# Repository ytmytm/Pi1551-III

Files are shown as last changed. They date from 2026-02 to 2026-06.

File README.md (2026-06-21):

# Pi1551-III

A **1551 floppy emulator** for Commodore C16, C116 and Plus/4, in the same mechanical and aesthetic package as the [C64 Pi1541-III](https://github.com/tebl/C64-Pi1541-III): Raspberry Pi 3–based, 1.3" OLED, rotary encoder, and stack of PCBs with faceplates. 

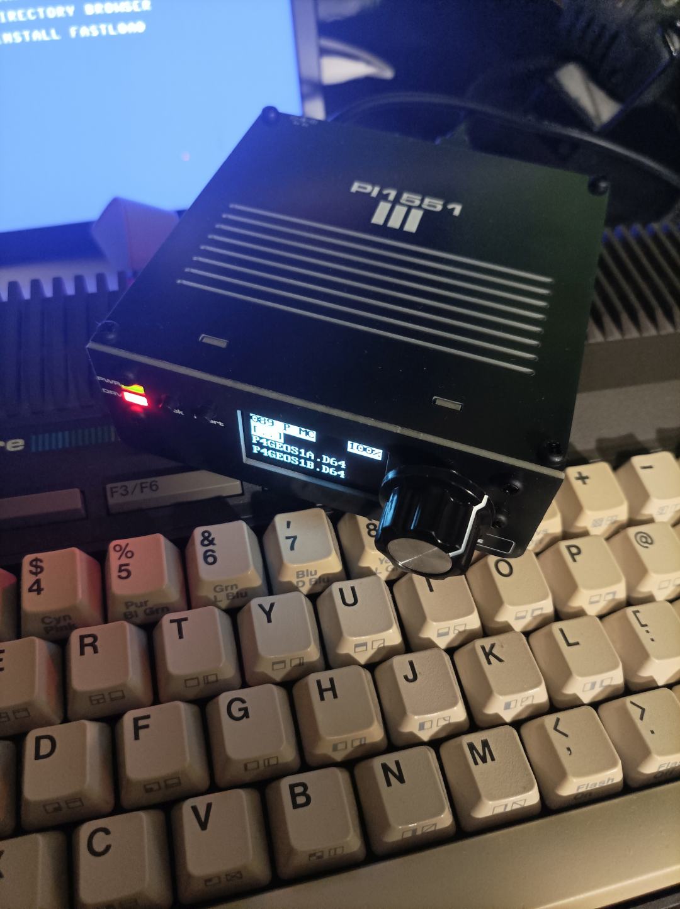
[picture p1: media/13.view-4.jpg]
Front view


This variant uses the **[Pi1551](https://github.com/ytmytm/Pi1551)** firmware and connects to the computer via **[tcbm2sd](https://github.com/ytmytm/plus4-tcbm2sd)** (TCBM bus). It also adds a **MiniDIN-7** port for **TAP tape playback** with a simple 1:1 male-to-male cable to the machine’s tape port.

> **WARNING — tcbm2sd only**  
> This device must **only** be connected to a **tcbm2sd** adapter. **Do not** connect it to an original 1551 paddle or any other 5 V bus. The interface is **not 5 V tolerant** and can damage the Raspberry Pi and the computer.

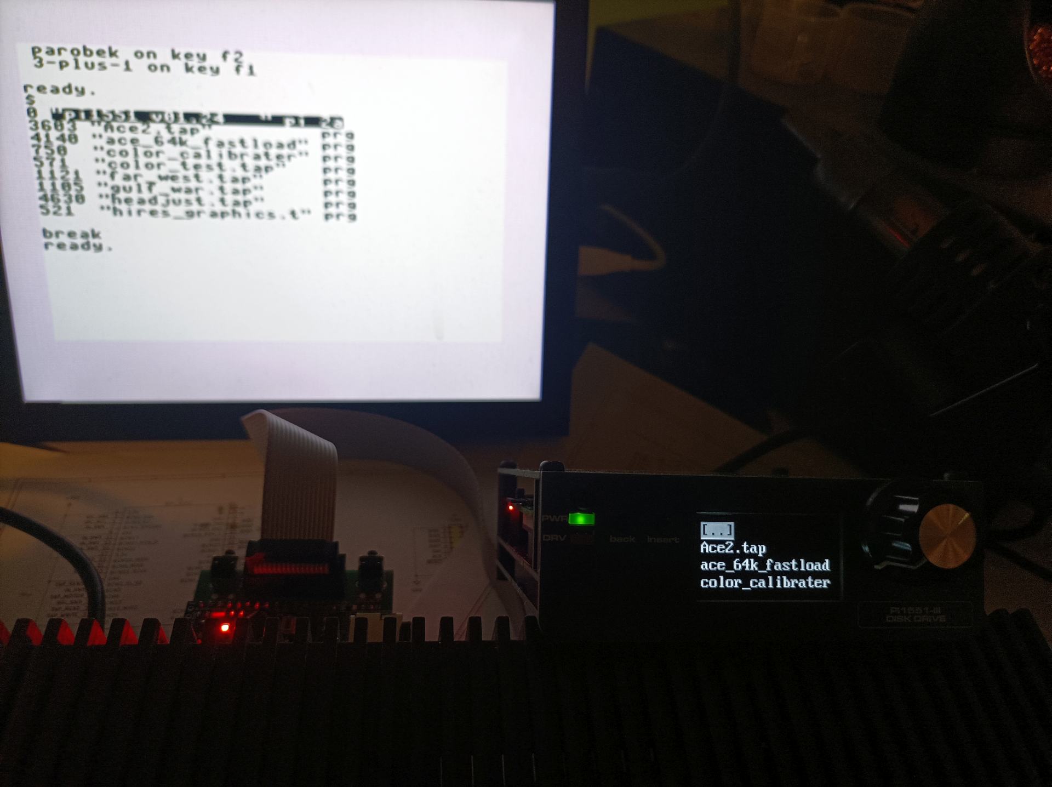
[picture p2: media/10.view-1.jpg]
PI1551-III view

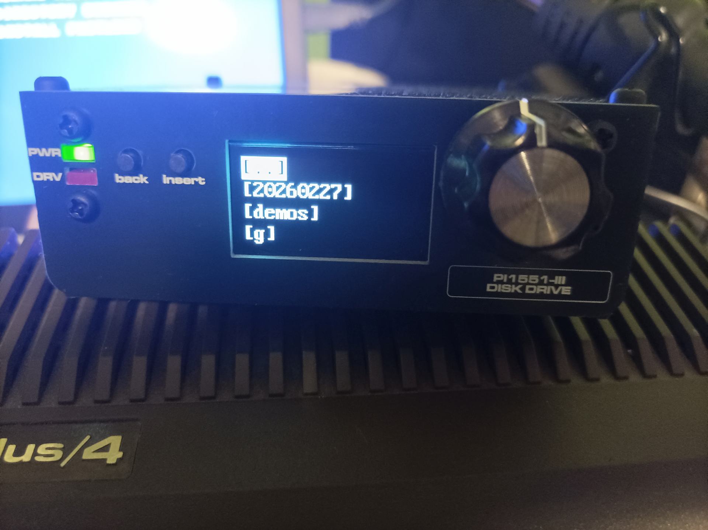
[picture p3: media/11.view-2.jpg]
PI1551-III view

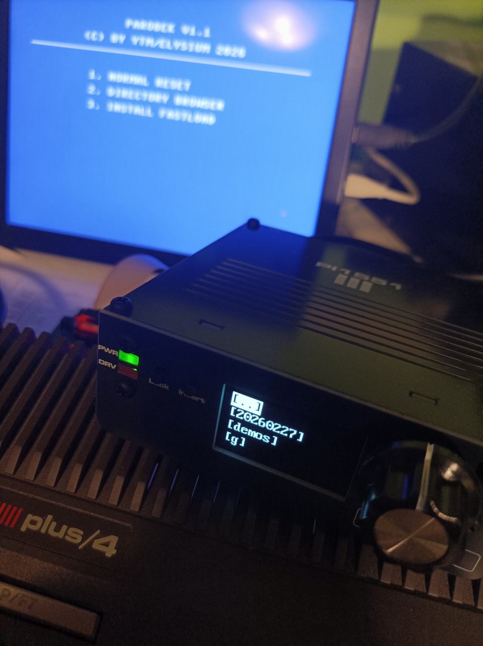
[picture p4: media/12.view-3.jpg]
PI1551-III view


---

**Build files:** Gerbers for every board, plus BOM and SMD position files for the main module (Pi1551-III Module-rotated), are published in the **[Releases](https://github.com/ytmytm/Pi1551-III/releases)** section of this repository.

If you prefer a smaller, simpler board: see **[Pi1551-HAT](https://github.com/ytmytm/Pi1551-HAT)** for a minimal Raspberry Pi HAT with the same 1551 + TAP functionality with several features optional.

---

- [1. Modules](#1-modules)
- [2. Differences from Pi1541-III](#2-differences-from-pi1541-iii)
- [3. Assembly](#3-assembly)
- [4. Cables](#4-cables)
- [5. Documentation](#5-documentation)
- [6. Resources](#6-resources)
- [7. Acknowledgements](#7-acknowledgements)

## 1. Modules

A complete Pi1551-III uses the same five-PCB stack as the Pi1541-III. Assembly and mechanical steps are almost identical, so **use the original project’s gallery and docs** for visual guidance:

- **[C64-Pi1541-III gallery](https://github.com/tebl/C64-Pi1541-III/tree/main/gallery)** — build photos, side views, and assembly reference.

Pi1541-III side view (assembly is the same)
(side view of Pi1541-III, almost identical to Pi1551-III)

| Module | Required | Description | Documentation | Build files |
|---|---|---|---|---|
| [Pi1551-III Module-rotated](Pi1551-III%20Module-rotated) | Yes | Main module: RPi 3, TCBM interface, optional power area (see below), MiniDIN-7 for TAP. | [BOM](Pi1551-III%20Module-rotated/README.md#3-bom) | [Releases](https://github.com/ytmytm/Pi1551-III/releases) |
| [Pi1551-III Module Panel](Pi1551-III%20Module%20Panel) | Yes | Front panel: OLED, rotary encoder, switches. | [BOM](Pi1551-III%20Module%20Panel/README.md#3-bom) | [Releases](https://github.com/ytmytm/Pi1551-III/releases) |
| [Pi1551-III Faceplate (FB1)](faceplates/Pi1551-III%20Module%20FB1) | Yes | Top faceplate; mechanical support for front panel. | — | [Releases](https://github.com/ytmytm/Pi1551-III/releases) |
| [Pi1551-III Faceplate (FB2)](faceplates/Pi1551-III%20Module%20FB2) | Recommended | Bottom faceplate; protects from shorts. | — | [Releases](https://github.com/ytmytm/Pi1551-III/releases) |
| [Pi1551-III Faceplate (FP1)](faceplates/Pi1551-III%20Module%20FP1) | Recommended | Front faceplate; cosmetic. | — | [Releases](https://github.com/ytmytm/Pi1551-III/releases) |

Each module’s BOM is in its README. For the main module, Gerbers, BOM and position files for SMD parts only are also in **Releases** for easy fabrication (e.g. JLCPCB).

## 2. Differences from Pi1541-III

- **Main module (“rotated”)**  
  The Raspberry Pi footprint is **rotated 180°** so **USB and HDMI are accessible** on the outside. I recommend **not** fitting the barrel jack (J1) or the 470 µF capacitor (C6): power the device from the **Raspberry Pi’s USB Micro** port with a good 5 V supply (e.g. 2 A). That avoids the extra power circuitry and is safe and sufficient.

- **1551 / TCBM**  
  The main module is adapted for **1551 emulation** and connects to the computer via a **TCBM bus connector** to a **[tcbm2sd](https://github.com/ytmytm/plus4-tcbm2sd)** adapter. Don't try to connect it to the original 1551 paddle - it will damage RaspberryPi.

- **TAP playback**  
  A **MiniDIN-7** port on the main module connects to the C16/C116/Plus/4 **tape port** with a MiniDIN-7 cable for TAP playback.

- **Branding**  
  Labels use the **Microgramma D Extended Bold** font for a consistent Commodore look.

## 3. Assembly

I had some trouble building the first unit, so here are some hints to make it easier:

1. Start with the [Pi1551-III Module-rotated](Pi1551-III%20Module-rotated):
  - Smallest elements first: SMD (if you solder them by hand), then buzzer, then RPi GPIO connector and TCBM bus connector for the ribbon cable, finally the MiniDIN-7 socket.
  - Since the USB power port is now accessible on the RPi, I recommend not installing the barrel jack or the 470 µF capacitor.
  - The capacitor can make the RPi’s HDMI port hard to use, depending on the plug.

2. Then continue with the [Pi1551-III Module Panel](Pi1551-III%20Module%20Panel):
  - Screw the bottom standoffs for mounting the faceplate **first** — it won’t be possible to turn them once the Module Panel is soldered to the base module.
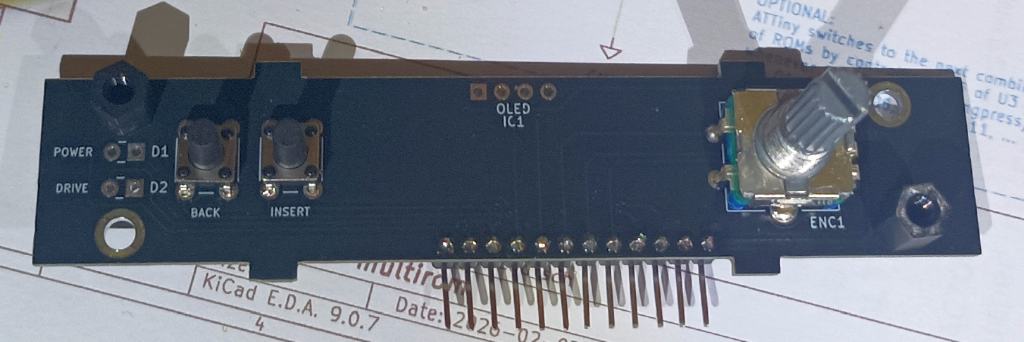
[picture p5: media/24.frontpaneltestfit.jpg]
  -  (bottom left standoff is missing on the photo)
  - Put solder blobs on JP3/JP4 to set up the OLED’s VCC and GND pin order according to your SH1106 module version.
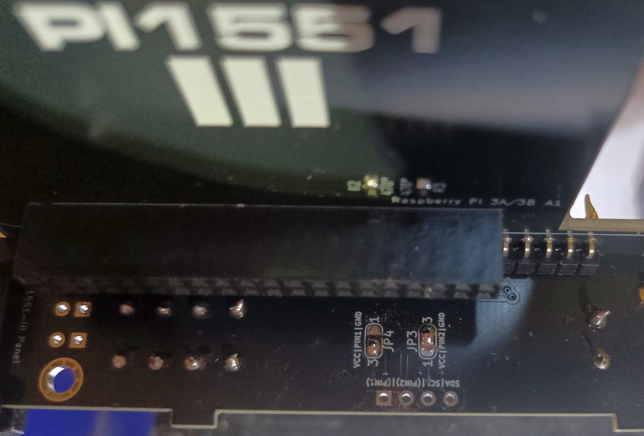
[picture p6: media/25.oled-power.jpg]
  - 
  - Do a test fit with the buttons (not soldered yet) and the faceplate to confirm their stems are long enough.
  - Solder in the buttons and rotary encoder, then test-fit the faceplate again.
  - Solder the right-angle pin headers to the faceplate. Make sure the two boards are aligned and square. This must happen before OLED screen.
  - Solder in the OLED screen; this is tricky because it must be at just the right distance from the PCB, parallel to it and aligned with the hole in the faceplate. I did the soldering with the faceplate screwed on; a piece of sticky foam behind the OLED to hold it in place can help.
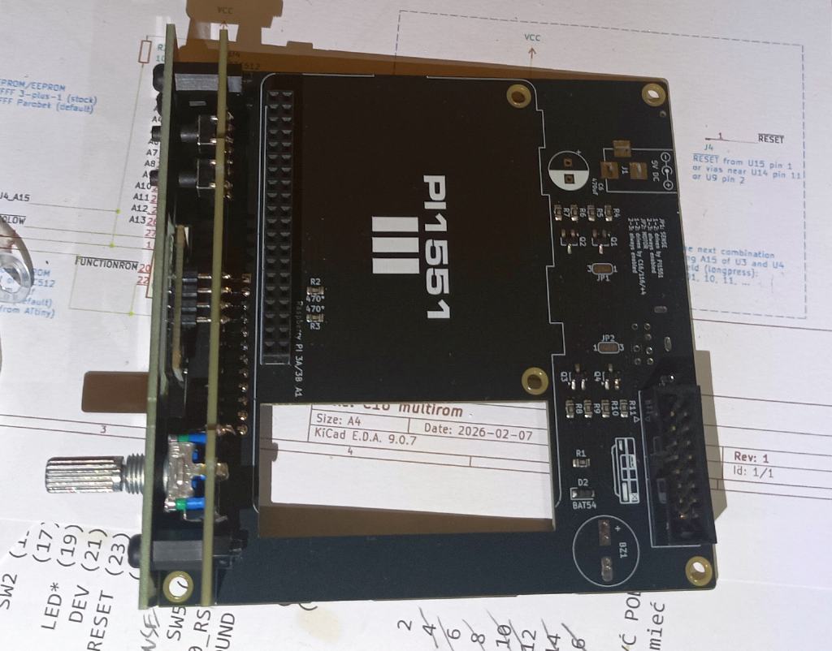
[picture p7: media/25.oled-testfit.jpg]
  - 
  - Solder in the rectangular LEDs — as with the OLED, align them with the holes in the faceplate so they sit flush. Their longer legs should be in the holes closer to the outer edge of the board; if you’re unsure about polarity, leave this until the two modules are connected with angled pin headers — with power on you can check which orientation lights the PWR LED.
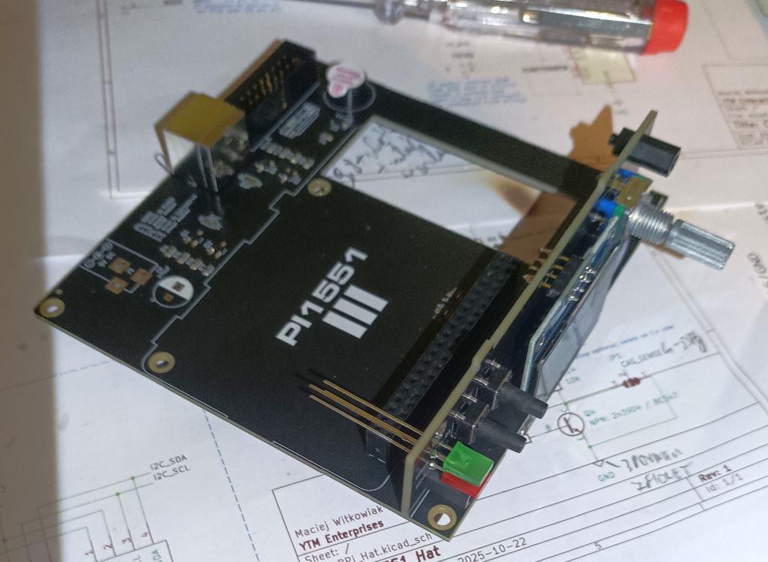
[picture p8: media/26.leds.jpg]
  - 
  - An authentic 1551 has a green PWR LED and red DRV LED, but their brightness differs a lot; rather than tweaking current-limiting resistors, I recommend using the same colour LED for both indicators.

3. Connect the modules together:
  - Fit the 12-pin right-angle pin headers so the short leg connects to the vertical PCB (Module Panel) and the longer legs go down through the horizontal PCB (Module-rotated).
  - Check that the PCBs are at the correct angle.
  - Ensure the standoffs in the Module Panel’s bottom holes are screwed in.
  - Then solder the first 1–2 pins on each end.
  - Check the angle again before soldering the rest.

At this point the device is basically complete and ready for testing. Remaining mechanical steps (faceplates, etc.) are illustrated in the **[C64-Pi1541-III gallery](https://github.com/tebl/C64-Pi1541-III/tree/main/gallery)** and [assembling one](https://github.com/tebl/C64-Pi1541-III/blob/main/documentation/assembling_one.md). For SD card preparation and firmware configuration, see the **[Pi1551](https://github.com/ytmytm/Pi1551)** project.

## 4. Cables

**TCBM (tcbm2sd):** Use a straight 16-wire ribbon cable; connections are 1:1 and both ends must be crimped the same way. On the Pi1551-III side the cable must be plugged in before the top cover is screwed on. I recommend crimping as in the photo below so the cable runs to the side opposite the plug’s tab, for easier routing.

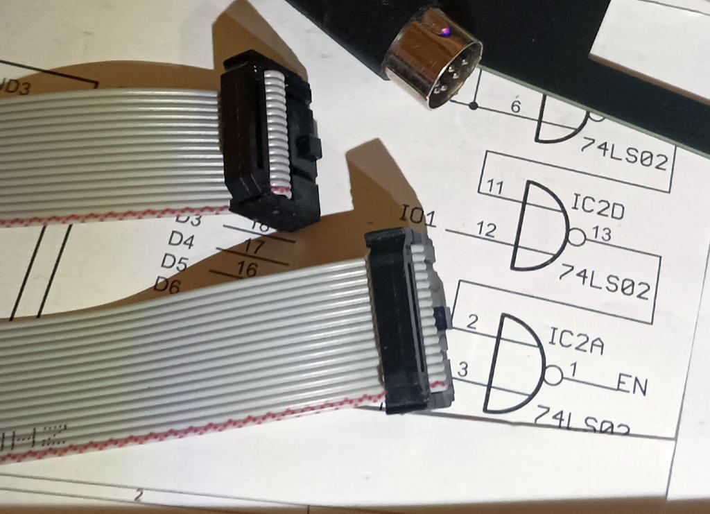
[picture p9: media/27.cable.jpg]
TCBM cable


**Tape (TAP):** You need a 1:1 male-to-male MiniDIN-7 cable. They are available on AliExpress, or you can solder one yourself. When buying a cable, note:
- Both plugs should be straight, not angled.
- The plug may not fit the Plus/4 if the round part of the MiniDIN doesn’t extend far enough from the rectangular body of the plug. Just shave off the corners from the square section. It may not look pretty but it will work. 

If your C16/C116/Plus/4 has a 6510 CPU swap, it cannot drive the tape MOTOR line; you can leave MOTOR enabled all the time in the [Pi1551](https://github.com/ytmytm/Pi1551) config (see [this note](https://hackjunk.com/2017/06/23/commodore-16-plus-4-8501-to-6510-cpu-conversion/)).

## 5. Documentation

SD card setup, configuration options, and firmware behaviour are described in the **[Pi1551](https://github.com/ytmytm/Pi1551)** project on GitHub.

- [Troubleshooting](documentation/troubleshooting.md)

## 6. Resources

- [C64 Pi1541-III](https://github.com/tebl/C64-Pi1541-III) — original design and gallery
- [Pi1551](https://github.com/ytmytm/Pi1551) — 1551 emulator firmware for Raspberry Pi
- [tcbm2sd](https://github.com/ytmytm/plus4-tcbm2sd) — TCBM adapter (connects Pi1551 to C16/C116/Plus/4)
- [Pi1551-HAT](https://github.com/ytmytm/Pi1551-HAT) — compact HAT alternative for 1551 + TAP
- [fat32format](http://ridgecrop.co.uk/index.htm?guiformat.htm) — format SD card as FAT32 (e.g. for Raspberry Pi boot)
- [SD Memory Card Formatter](https://www.sdcard.org/downloads/formatter/) — SD Association tool for formatting SD/SDHC/SDXC cards (Windows/Mac/Linux)

## 7. Acknowledgements

The Pi1551-III mechanical design, panel, and faceplates are derived from **[tebl](https://github.com/tebl)**’s [C64-Pi1541-III](https://github.com/tebl/C64-Pi1541-III), which in turn builds on **Steve White**’s [Pi1541](https://cbm-pi1541.firebaseapp.com/) software.

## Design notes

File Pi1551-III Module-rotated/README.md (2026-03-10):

# Pi1551-III Module-rotated
This is the main PCB and holds most of the active components. It is designed to be used with [Pi1551-III Module Panel](../Pi1551-III%20Module%20Panel) (see its [BOM](../Pi1551-III%20Module%20Panel/README.md#3-bom) when ordering). The Raspberry Pi footprint is rotated 180° so USB and HDMI are accessible; we recommend **not** installing the barrel jack (J1) or the 470 µF capacitor (C6)—power the device from the Raspberry Pi’s USB Micro port.

- [1> Build instructions](#1-build-instructions)
- [2> Schematic](#2-schematic)
- [3> BOM](#3-bom)

# 1> Build instructions
Assembly of this module is described in the top-level [README Assembly section](../README.md#3-assembly): start with the smallest parts first (SMD if hand-soldering, then buzzer, RPi GPIO header, TCBM connector, MiniDIN-7). The BOM for this module is [below](#3-bom).

# 2> Schematic
The supplied KiCad files should be sufficient as both a schematic and as a  starting point for ordering PCBs (basically you could just zip the contents of the export folder and upload that on a fabrication site), the schematic is also available in [PDF-format](../documentation/schematic) (if present in this repo) for when things don’t work as expected after assembly.

# 3> BOM
This BOM matches the schematic in this folder. Optional parts in parentheses. Gerbers, a BOM with JLCPCB part numbers, and SMD position data are in the [Releases](https://github.com/ytmytm/Pi1551-III/releases) section.

| Reference | Item | Count | Order  |
| --- | --- | ----- | --- |
| Module PCB | PCB for this project | 1 | [Releases](https://github.com/ytmytm/Pi1551-III/releases)
| Faceplate FB1 | Top faceplate PCB | 1 | [Releases](https://github.com/ytmytm/Pi1551-III/releases)
| Faceplate FB2 | Bottom faceplate PCB |  (1)  | [Releases](https://github.com/ytmytm/Pi1551-III/releases)
| A1 | 2×20 pin female header (RPi GPIO) | 1 |
| | Raspberry Pi 3A / 3B / 3B+ | 1 |
| BZ1 | Passive buzzer (pin spacing 3.81–7 mm) |  (1)  |
| C6 | 470 µF electrolytic (8 mm × 3.5 mm) |  (1)* |
| D2 | Schottky diode (BAT54, BAS40, 1N5819, etc.) SMD SOD-123 — protects Pi | 1 |
| J1 | 2.1 mm × 5.5 mm barrel jack |  (1)* |
| J3 | 2×8 (16-pin) IDC connector, vertical (ribbon to tcbm2sd) | 1 |
| J4 | MiniDIN-7 female socket (tape/TAP) | 1 |
| J8 | [Pi1551-III Module Panel](../Pi1551-III%20Module%20Panel) (assembled) | 1 |
| JP1, JP2 | Solder jumpers (on PCB; set per schematic) | 2 |
| Q1–Q4 | MMBT3904 or 2N3904 (SOT-23 SMD) — TAP circuit | 4 |
| R1 | 3.3 kΩ (0805 or similar SMD) — with D2 | 1 |
| R2, R3 *1 | 470 Ω (0805 SMD) — for panel LEDs | 2 |
| R4–R24 | 3.3 kΩ (0805 SMD) — TAP / level shifting, pullups | 21 |
| Mounting *2 | Nylon M3 hex standoffs 6mm (M-F) | 4 |
| Mounting *2 | Nylon M3 hex standoffs 8mm (M-F) | 2 |
| Mounting *3 | Nylon M3 hex standoffs 12mm (M-F) | (4)|
| Mounting *2 | Nylon M3 hex standoffs 20mm (M-F) | 4 |
| Mounting *2 | Nylon M3x6mm nylon screws | 6 |
| Mounting *2 | Nylon M3x6mm nylon nuts | 12 |

**\*** Recommended not to install J1 (barrel jack) or C6 (470 µF). Power the device from the Raspberry Pi’s USB Micro port.

**D2 (Schottky):** Orient with the cathode stripe towards the silkscreen mark.

1) For LEDs on [Pi1551-III Module Panel](../Pi1551-III%20Module%20Panel); 470 Ω suits most coloured LEDs — use a higher value for blue or "bright" types.
2) M3 nylon standoff kits usually contain what you need; check quantities.
3) Only when *not* installing bottom faceplate ([Pi1551-III Faceplate FB2](../faceplates/Pi1551-III%20Module%20FB2)).

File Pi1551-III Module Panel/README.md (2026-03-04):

# Pi1551-III Module Panel
This PCB holds the front-panel components and mounts on the [Pi1551-III Module-rotated](../Pi1551-III%20Module-rotated). It has its own BOM; order parts for both this panel and the main module to build a complete device.

- [1> Build instructions](#1-build-instructions)
- [2> Schematic](#2-schematic)
- [3> BOM](#3-bom)

Current PCB

# 1> Build instructions
Assembly of this panel is described in the top-level [README Assembly section](../README.md#3-assembly) (step 2). The BOM for this module is [below](#3-bom). For more photos and the same mechanical steps, see the [C64-Pi1541-III gallery](https://github.com/tebl/C64-Pi1541-III/tree/main/gallery).

# 2> Schematic
The supplied KiCad files should be sufficient as both a schematic and as a  starting point for ordering PCBs (basically you could just zip the contents of the export folder and upload that on a fabrication site), the schematic is also available in [PDF-format](../documentation/schematic) (if present in this repo) for when things don’t work as expected after assembly.

# 3> BOM
This BOM matches the schematic in this folder. Optional parts in parentheses. Build files (Gerbers, etc.) are in the [Releases](https://github.com/ytmytm/Pi1551-III/releases) section.

| Reference | Item | Count | Order  |
| --- | --- | ----- | --- |
| Module Panel PCB | PCB specific to this project | 1 | [Releases](https://github.com/ytmytm/Pi1551-III/releases)
| Faceplate (FP1) PCB | Front faceplate | (1)| [Releases](https://github.com/ytmytm/Pi1551-III/releases)
| IC1 *1 | SH1106 I2C OLED 128x64 (1.3") | 1 |
| ENC1 | EC11 rotary encoder, 20mm. Preferably plum handle. | 1 |
| | Suitable knob for rotary encoder, max 20mm in diameter. | (1)|
| D1,D2 | 2x5x7mm rectangular LED, suitably coloured. | 2 |
| J1 | 12-pin right-angle pin header | 1 |
| SW1,SW2 | 6x6mm momentary switch, 10.5mm or taller. | 2 |
| Mounting *2 | Nylon M3 hex standoffs 8mm (M-F) | 4 |
| Mounting *2 | Nylon M3x6mm nylon screws | 4 |
| Mounting *2 | Nylon M3x6mm nylon nuts | 4 |

1) Many of these will be listed for sale as 1.3" ssd1306-based OLED displays, but they actually have the slightly different sh1106-controller. Something to keep in mind when ordering.
2) These are used in various places of the project, these are available in the form of kits usually advertised *M3 nylon standoff kit* which should contain most of what you'd need though you should check that they include them in sufficient quantity.

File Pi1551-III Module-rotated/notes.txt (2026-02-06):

Mini-Din-7 https://forum.kicad.info/t/mini-din-connectors-their-footprints-and-3-d-models-asking-for-discussion-and-a-bit-of-help-discussion/58247/11

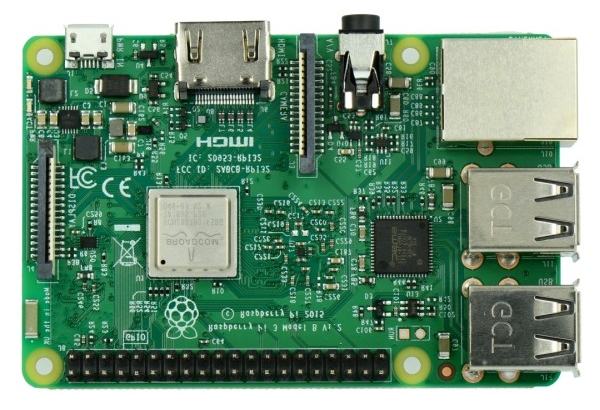
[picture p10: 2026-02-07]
Pi1551-III Module-rotated/raspberry-pi-3-model-b-top-flip.jpg

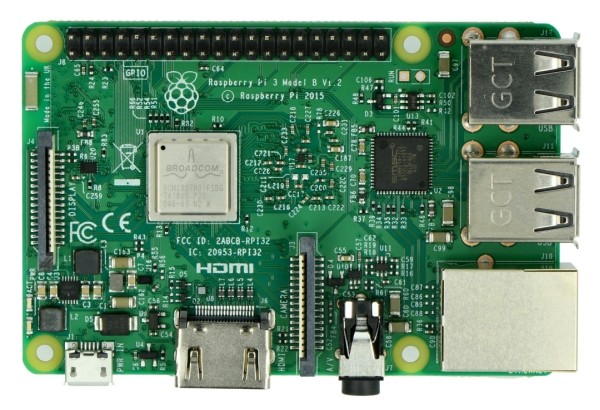
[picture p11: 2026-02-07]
Pi1551-III Module-rotated/raspberry-pi-3-model-b-top.jpg

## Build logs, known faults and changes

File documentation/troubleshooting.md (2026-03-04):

# 1> Troubleshooting

If something has gone wrong, work through the basics first.

**Power.** Underpowered supplies often cause flaky behaviour. Power the Pi1551-III from the **Raspberry Pi’s USB Micro** port with a good **5 V, at least 2 A** supply. Cheap adapters can fail or damage the Pi over time; use a known-good PSU.

**Display.** If the OLED is completely dark, take the Pi out and start it with HDMI connected to a monitor. Black or rainbow screen? Check the SD card — any difference with the card in or out? Many cards ship as **exFAT**; the Pi boots only from **FAT32**. Format the card with [fat32format](http://ridgecrop.co.uk/index.htm?guiformat.htm) or the [SD Memory Card Formatter](https://www.sdcard.org/downloads/formatter/) (do not format the wrong drive).

**OLED still dark** after that? Check **JP3/JP4** on the [Pi1551-III Module Panel](../Pi1551-III%20Module%20Panel) — they set the OLED’s VCC/GND pin order for your SH1106 module. Match them to your display’s pinout. If you had them wrong and already powered up, the display may be damaged (replace it). **Graphical glitches** usually mean the display is configured as *ssd1306* in options; most 1.3" modules are actually **sh1106** — set the display type to sh1106 in the [Pi1551](https://github.com/ytmytm/Pi1551) configuration.

**Firmware and configuration.** SD card layout, options, and behaviour are documented in the **[Pi1551](https://github.com/ytmytm/Pi1551)** project on GitHub. For loading issues, config, or TAP, check that project’s docs and issues.

**Quick test.** Once the device runs, pick a D64 from the SD card and start emulation. On the Commodore 16, C116 or Plus/4, try:
```
DIRECTORY
```
to confirm the 1551 is responding.

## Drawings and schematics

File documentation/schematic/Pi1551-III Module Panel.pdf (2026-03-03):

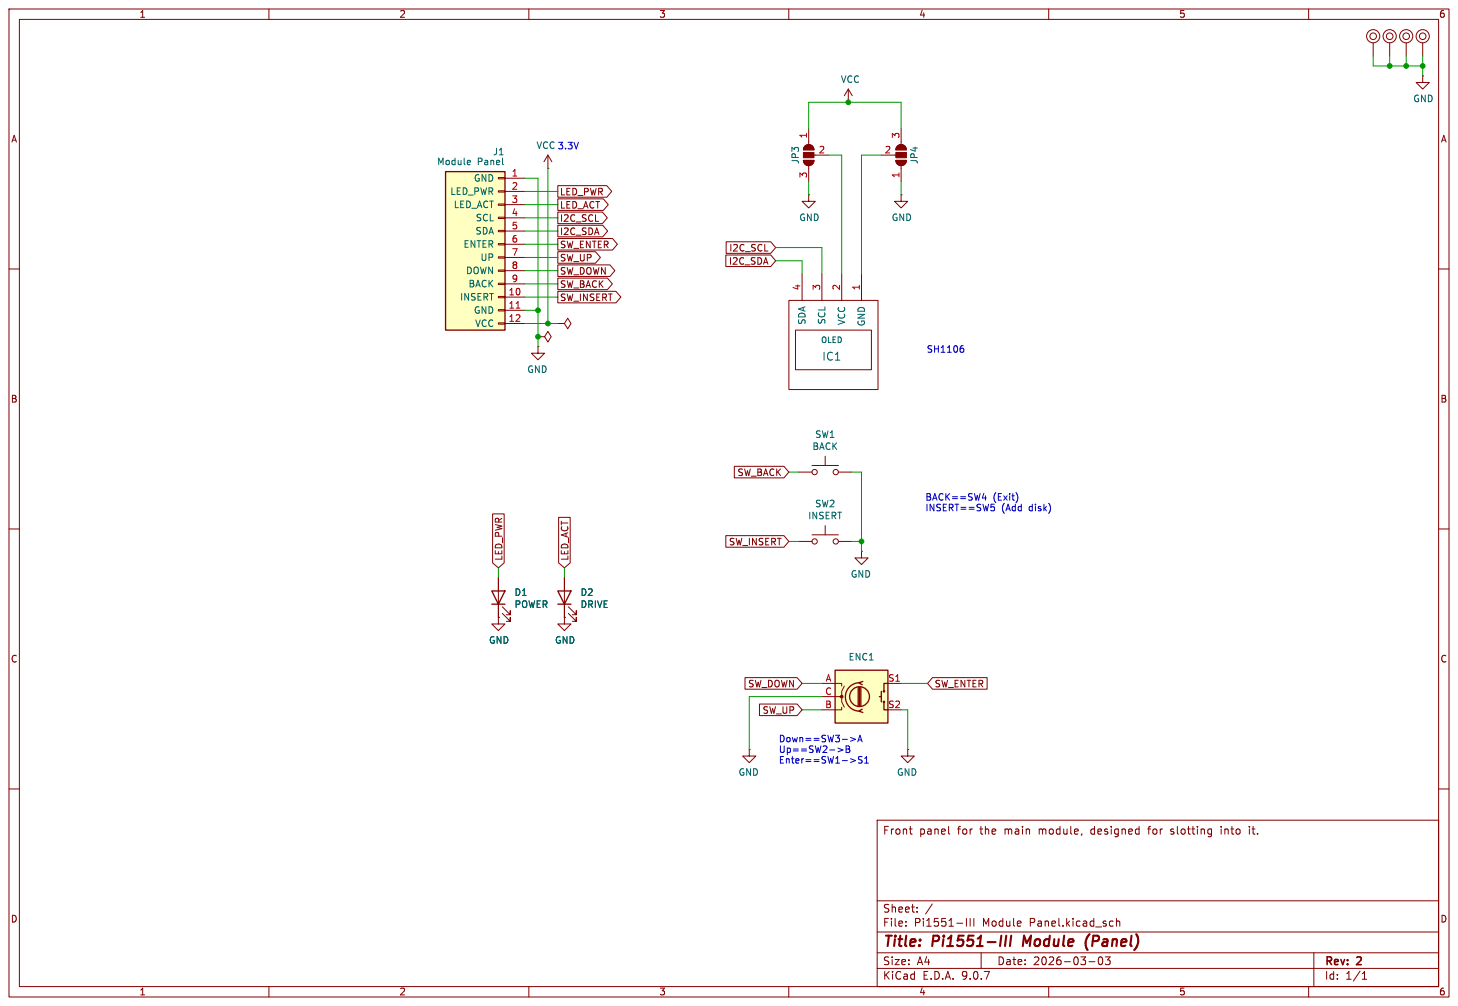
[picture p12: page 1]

INSERT==SW5 (Add disk) SH1106 Down==SW3->A Up==SW2->B

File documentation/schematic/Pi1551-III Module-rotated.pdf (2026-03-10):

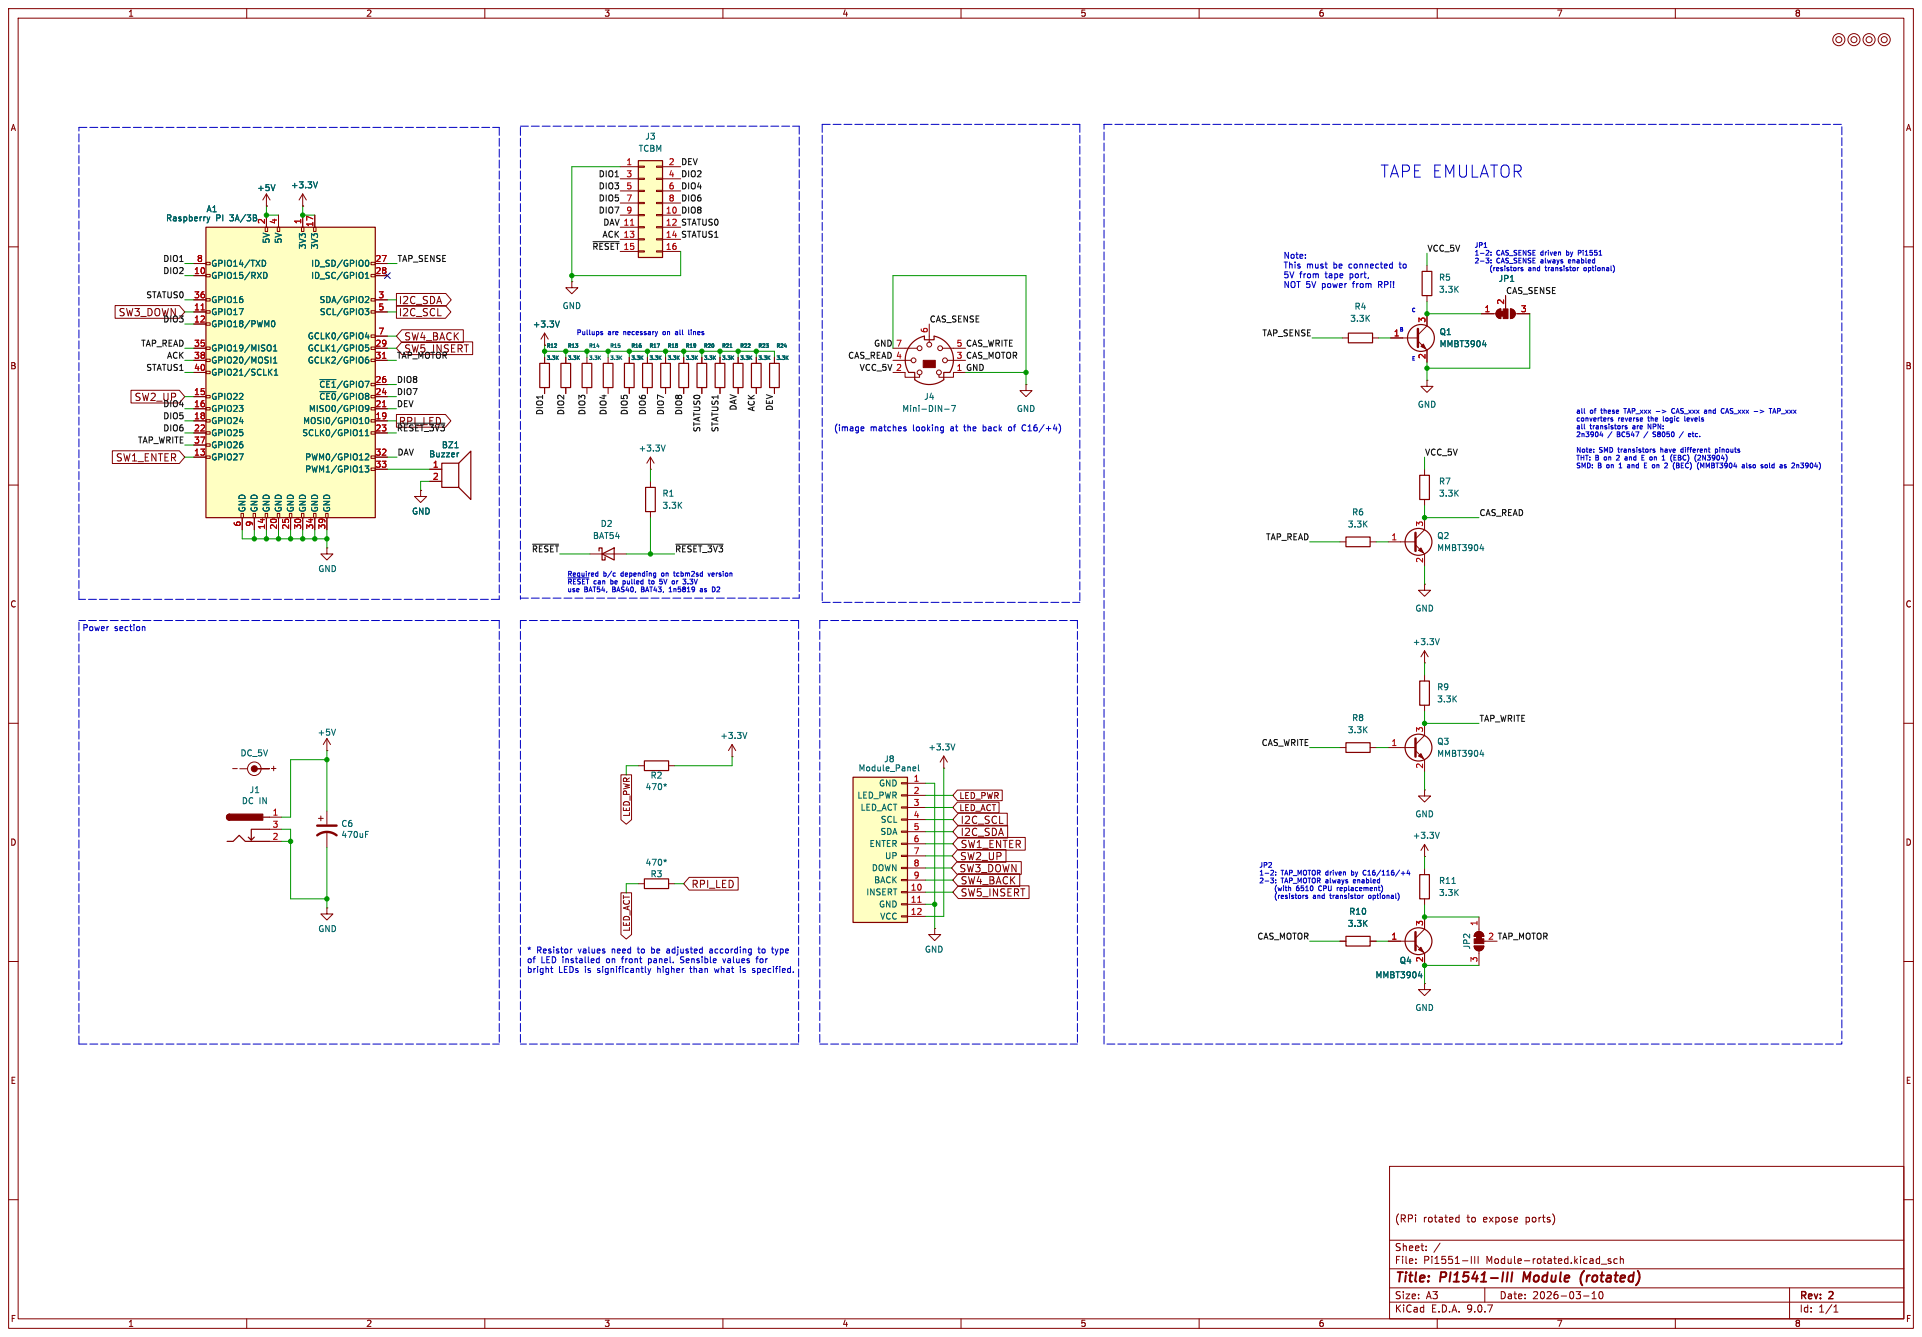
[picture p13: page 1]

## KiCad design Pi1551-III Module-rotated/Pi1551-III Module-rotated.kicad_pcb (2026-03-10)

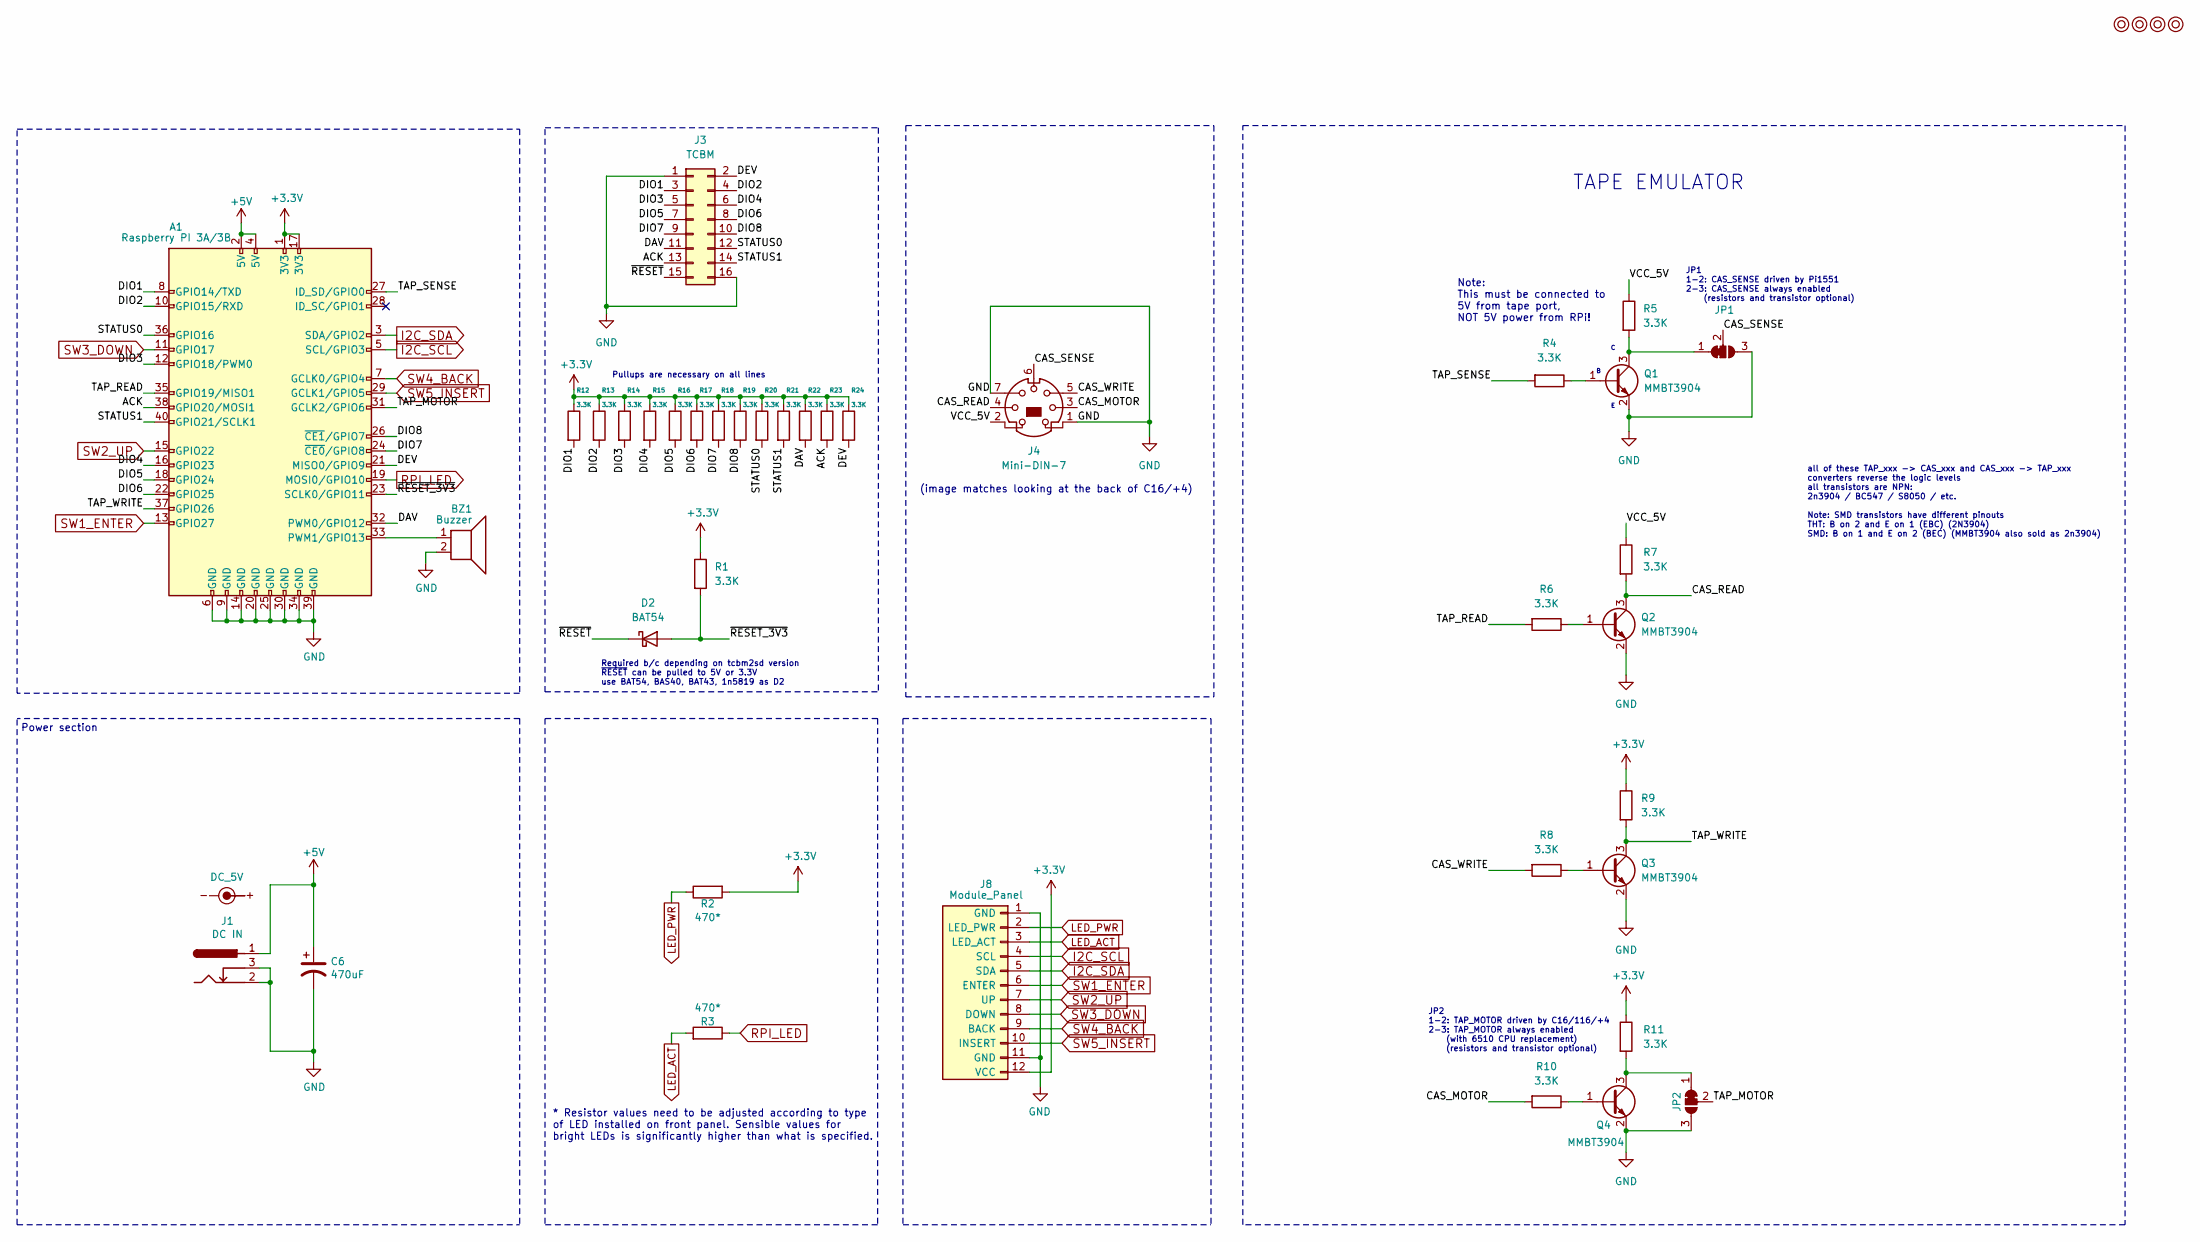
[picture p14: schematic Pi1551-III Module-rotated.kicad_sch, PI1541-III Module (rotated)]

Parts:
A1: Raspberry PI 3A/3B; Raspberry_Pi_3B_Socketed_THT_FaceDown_MountingHoles
BZ1: Buzzer; Buzzer_12x9.5RM7.6
C6: 470uF; CP_Radial_D8.0mm_P3.50mm
D2: BAT54; D_SOD-123; MFR.Part # BAT54W; JLCPCB Part # C7502705
J1: DC IN; BARREL_JACK
J3: TCBM; IDC-Header_2x08_P2.54mm_Vertical
J4: Mini-DIN-7; Mini_DIN_round_7_canned
J8: Module_Panel
JP1, JP2: SolderJumper_3_Bridged12; SolderJumper-3_P1.3mm_Bridged12_RoundedPad1.0x1.5mm_NumberL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
M1, M2, M3, M4: Mounting; M3
Q1, Q2, Q3, Q4: MMBT3904; SOT-23_Handsoldering; MFR.Part # 2N3904S-RTK/PS; JLCPCB Part # C18536
R1, R4, R5, R6, R7, R8, R9, R10, R11, R12, R13, R14, R15, R16, R17, R18, R19, R20, R21, R22, R23, R24: 3.3K; R_0805_2012Metric_Pad1.20x1.40mm_HandSolder; MFR.Part # 0805W8F3301T5E; JLCPCB Part # C26010
R2, R3: 470*; R_0805_2012Metric_Pad1.20x1.40mm_HandSolder; MFR.Part # 0805W8F4700T5E; JLCPCB Part # C17710
SYM1: DC_5V; PWR_Specification

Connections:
+3.3V: A1.1 (3V3), A1.17 (3V3), J8.12 (VCC), R1.1, R2.2, R9.1, R11.1, R12.1, R13.1, R14.1, R15.1, R16.1, R17.1, R18.1, R19.1, R20.1, R21.1, R22.1, R23.1, R24.1
+5V: A1.2 (5V), A1.4 (5V), C6.1, J1.1
/ACK: A1.38 (GPIO20/MOSI1), J3.13, R23.2
/CAS_MOTOR: J4.3, R10.2
/CAS_READ: J4.4, Q2.3 (C), R7.2
/CAS_SENSE: J4.6, JP1.2 (C)
/CAS_WRITE: J4.5, R8.2
/DAV: A1.32 (PWM0/GPIO12), J3.11, R22.2
/DEV: A1.21 (MISO0/GPIO9), J3.2, R24.2
/DIO1: A1.8 (GPIO14/TXD), J3.3, R12.2
/DIO2: A1.10 (GPIO15/RXD), J3.4, R13.2
/DIO3: A1.12 (GPIO18/PWM0), J3.5, R14.2
/DIO4: A1.16 (GPIO23), J3.6, R15.2
/DIO5: A1.18 (GPIO24), J3.7, R16.2
/DIO6: A1.22 (GPIO25), J3.8, R17.2
/DIO7: A1.24 (~CE0/GPIO8), J3.9, R18.2
/DIO8: A1.26 (~CE1/GPIO7), J3.10, R19.2
/STATUS0: A1.36 (GPIO16), J3.12, R20.2
/STATUS1: A1.40 (GPIO21/SCLK1), J3.14, R21.2
/TAP_MOTOR: A1.31 (GCLK2/GPIO6), JP2.2 (C)
/TAP_READ: A1.35 (GPIO19/MISO1), R6.2
/TAP_SENSE: A1.27 (ID_SD/GPIO0), R4.2
/TAP_WRITE: A1.37 (GPIO26), Q3.3 (C), R9.2
/VCC_5V: J4.2, R5.1, R7.1
/~RESET_3V3: A1.23 (SCLK0/GPIO11), D2.2 (A), R1.2
/~RESET: D2.1 (K), J3.15
GND: A1.6 (GND), A1.9 (GND), A1.14 (GND), A1.20 (GND), A1.25 (GND), A1.30 (GND), A1.34 (GND), A1.39 (GND), BZ1.2, C6.2, J1.2, J1.3, J3.1, J3.16, J4.1, J4.7, J8.1 (GND), J8.11 (GND), JP1.3 (B), JP2.3 (B), Q1.2 (E), Q2.2 (E), Q3.2 (E), Q4.2 (E)
I2C_SCL: A1.5 (SCL/GPIO3), J8.4 (SCL)
I2C_SDA: A1.3 (SDA/GPIO2), J8.5 (SDA)
LED_ACT: J8.3 (LED_ACT), R3.2
LED_PWR: J8.2 (LED_PWR), R2.1
unnamed: A1.33 (PWM1/GPIO13), BZ1.1
unnamed: JP1.1 (A), Q1.3 (C), R5.2
unnamed: JP2.1 (A), Q4.3 (C), R11.2
unnamed: Q1.1 (B), R4.1
unnamed: Q2.1 (B), R6.1
unnamed: Q3.1 (B), R8.1
unnamed: Q4.1 (B), R10.1
RPI_LED: A1.19 (MOSI0/GPIO10), R3.1
SW1_ENTER: A1.13 (GPIO27), J8.6 (ENTER)
SW2_UP: A1.15 (GPIO22), J8.7 (UP)
SW3_DOWN: A1.11 (GPIO17), J8.8 (DOWN)
SW4_BACK: A1.7 (GCLK0/GPIO4), J8.9 (BACK)
SW5_INSERT: A1.29 (GCLK1/GPIO5), J8.10 (INSERT)

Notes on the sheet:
Pullups are necessary on all lines
(image matches looking at the back of C16/+4)
Required b/c depending on tcbm2sd version ~{RESET} can be pulled to 5V or 3.3V use BAT54, BAS40, BAT43, 1n5819 as D2
* Resistor values need to be adjusted according to type of LED installed on front panel. Sensible values for bright LEDs is significantly higher than what is specified.
all of these TAP_xxx -> CAS_xxx and CAS_xxx -> TAP_xxx converters reverse the logic levels all transistors are NPN: 2n3904 / BC547 / S8050 / etc. Note: SMD transistors have different pinouts THT: B on 2 and E on 1 (EBC) (2N3904) SMD: B on 1 and E on 2 (BEC) (MMBT3904 also sold as 2n3904)
Note: This must be connected to 5V from tape port, NOT 5V power from RPi!
TAPE EMULATOR
Power section
JP2 1-2: TAP_MOTOR driven by C16/116/+4 2-3: TAP_MOTOR always enabled (with 6510 CPU replacement) (resistors and transistor optional)
JP1 1-2: CAS_SENSE driven by Pi1551 2-3: CAS_SENSE always enabled (resistors and transistor optional)

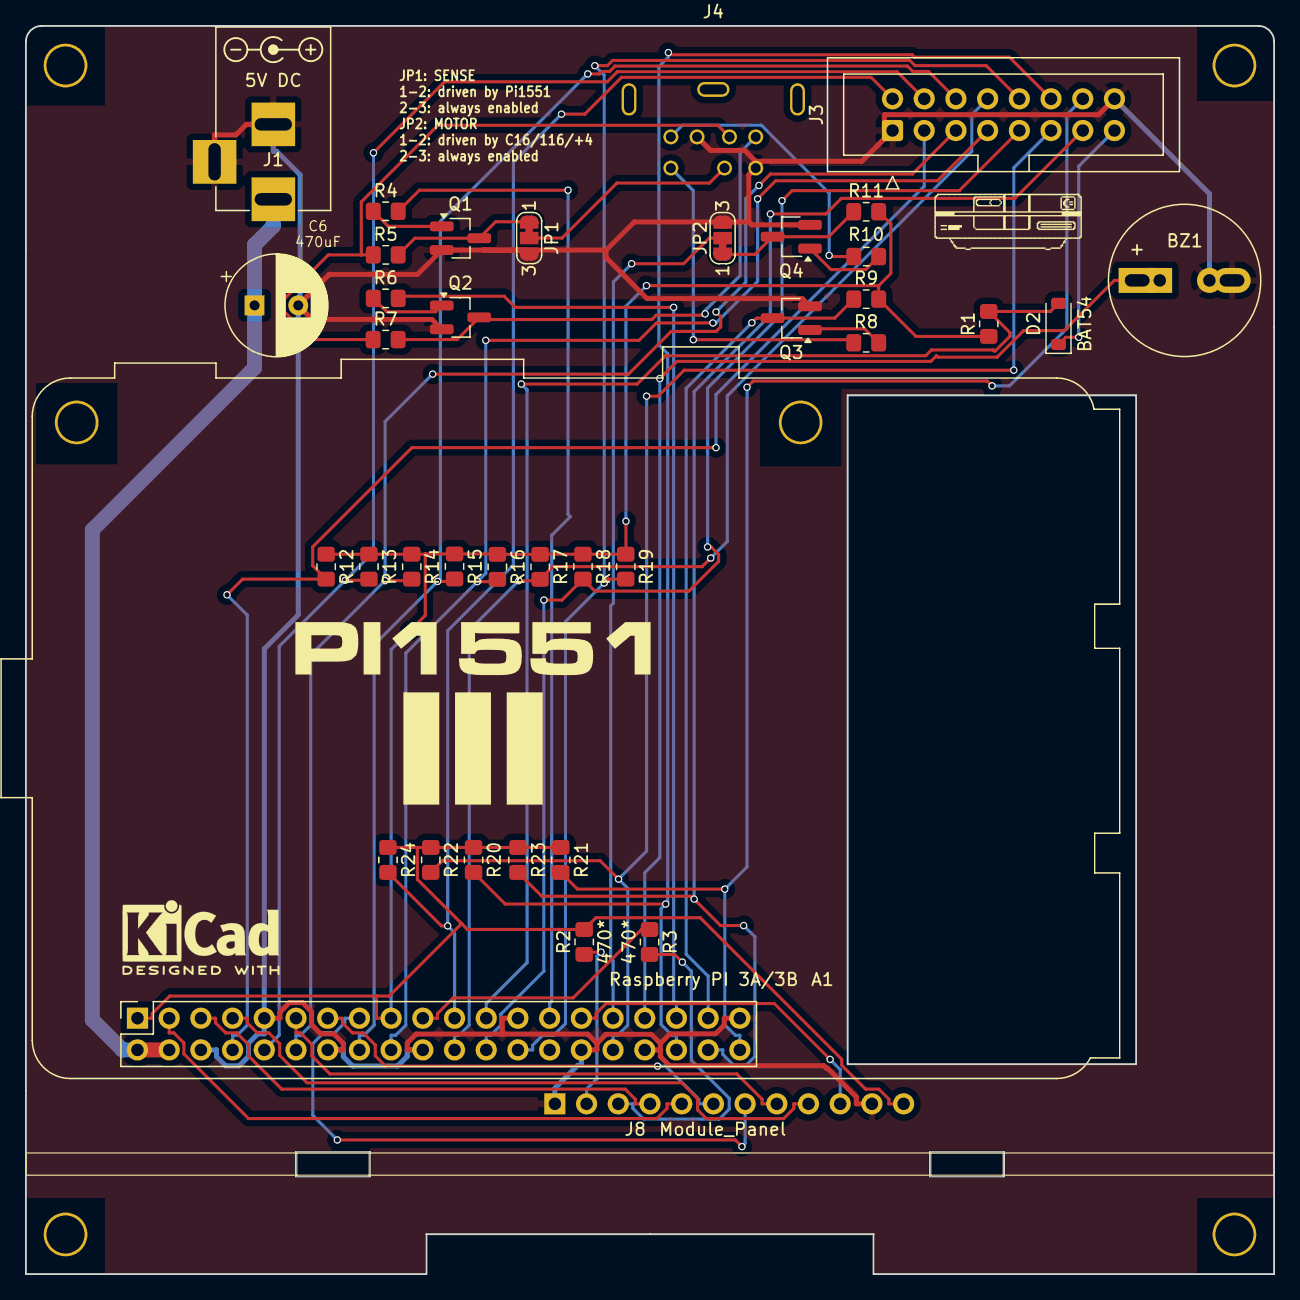
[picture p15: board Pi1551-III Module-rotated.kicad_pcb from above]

Board: 2 copper layers, 100.0 x 100.0 mm, 48 parts (1 on the bottom side), 44 nets.

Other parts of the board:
Pi1541-drive: Pi1541-drive
REF1, REF2: KiCad-Logo2_6mm_SilkScreen
kibuzzard-69864AC5: G***; kibuzzard-69864AC5
kibuzzard-69864AE8: G***; kibuzzard-69864AE8

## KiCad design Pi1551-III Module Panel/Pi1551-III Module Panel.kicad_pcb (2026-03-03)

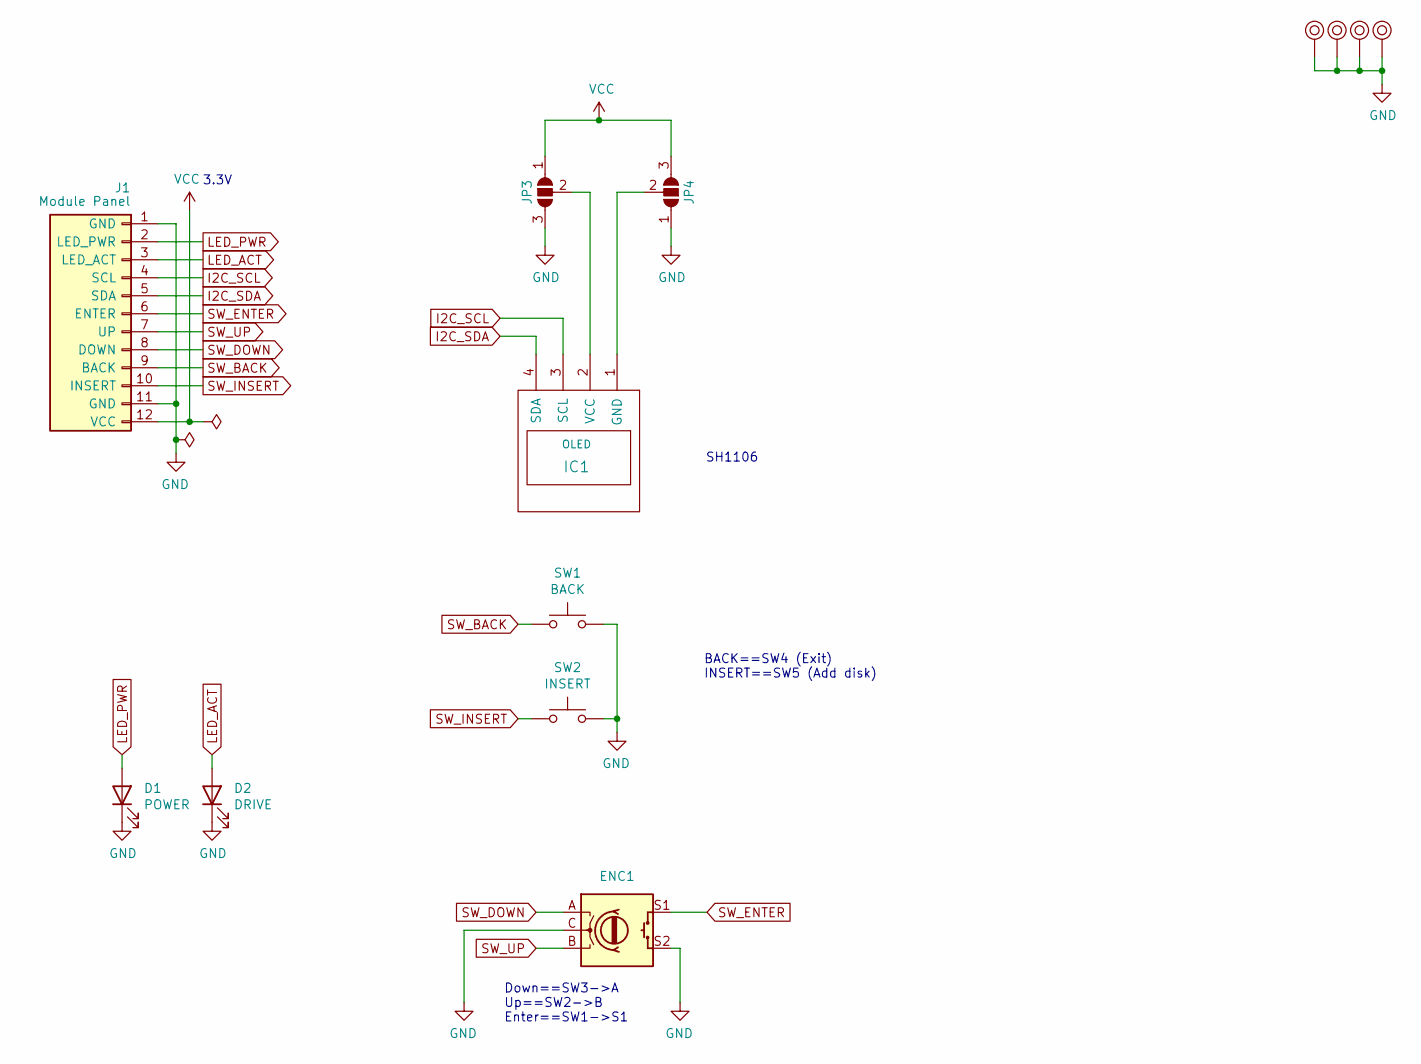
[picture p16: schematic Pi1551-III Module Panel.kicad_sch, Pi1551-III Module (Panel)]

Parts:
D1: POWER; LED_Rectangular_W3.0mm_H2.0mm
D2: DRIVE; LED_Rectangular_W3.0mm_H2.0mm
ENC1: RotaryEncoder_Switch; RotaryEncoder_Alps_EC11E-Switch_Vertical_H20mm_CircularMoun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; MFR.Part # EC11E15244B2; JLCPCB Part # C470754
IC1: OLED; 1.3_I2C_OLED_No_mounting
J1: Module Panel; PinHeader_1x12_P2.54mm_Horizontal
JP3, JP4: SolderJumper_3_Open; SolderJumper-3_P1.3mm_Open_RoundedPad1.0x1.5mm_NumberLabels
M1, M2, M3, M4: Mounting_Pin; M3_pin
SW1: BACK; SW_PUSH_6mm
SW2: INSERT; SW_PUSH_6mm

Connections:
GND: D1.1 (K), D2.1 (K), ENC1.C, ENC1.S2, J1.1 (GND), J1.11 (GND), JP3.3 (B), JP4.1 (A), M1.1, M2.1, M3.1, M4.1, SW1.2, SW2.2
I2C_SCL: IC1.3 (SCL), J1.4 (SCL)
I2C_SDA: IC1.4 (SDA), J1.5 (SDA)
LED_ACT: D2.2 (A), J1.3 (LED_ACT)
LED_PWR: D1.2 (A), J1.2 (LED_PWR)
unnamed: IC1.1 (GND), JP4.2 (C)
unnamed: IC1.2 (VCC), JP3.2 (C)
SW_BACK: J1.9 (BACK), SW1.1
SW_DOWN: ENC1.A, J1.8 (DOWN)
SW_ENTER: ENC1.S1, J1.6 (ENTER)
SW_INSERT: J1.10 (INSERT), SW2.1
SW_UP: ENC1.B, J1.7 (UP)
VCC: J1.12 (VCC), JP3.1 (A), JP4.3 (B)

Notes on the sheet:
BACK==SW4 (Exit) INSERT==SW5 (Add disk)
SH1106
Down==SW3->A Up==SW2->B Enter==SW1->S1
3.3V

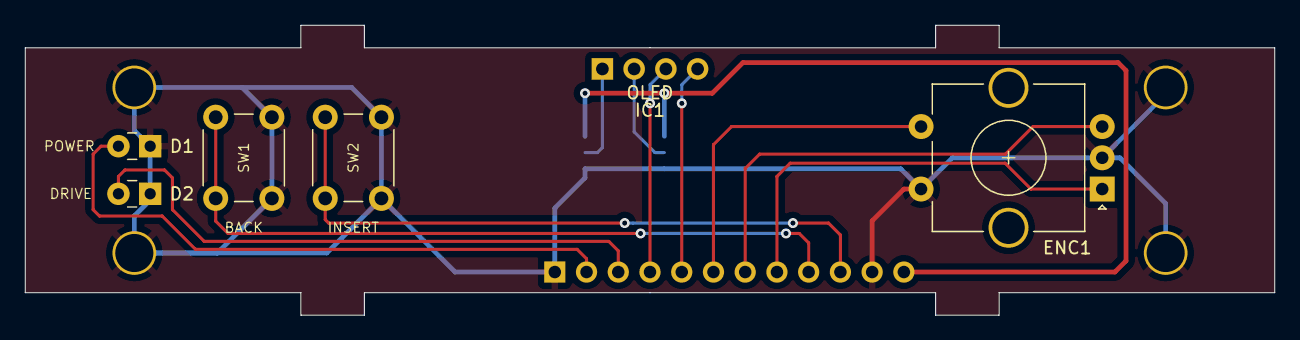
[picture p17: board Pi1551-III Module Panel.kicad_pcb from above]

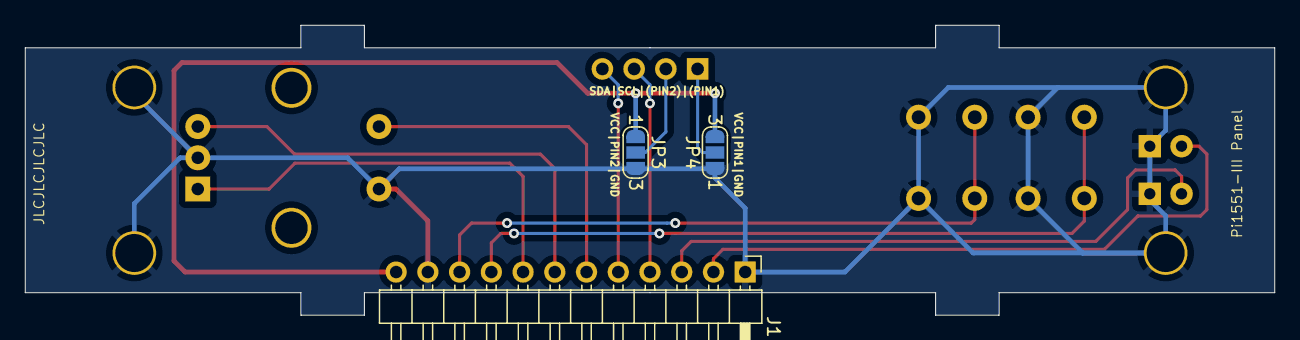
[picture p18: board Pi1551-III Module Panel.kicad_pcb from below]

Board: 2 copper layers, 100.0 x 23.2 mm, 13 parts (3 on the bottom side), 13 nets.

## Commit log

2026-02-02 rebranding to Pi1551-III
    [C64 Pi1541-III Module FB1.sch, C64 Pi1541-III Module Panel.sch, Pi1551-III Module FB1.kicad_pcb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]
2026-02-02 upgrade to KiCad 9.0.7
    [Pi1551-III Module FB1.kicad_pcb, Pi1551-III Module FB1.kicad_sch, Pi1551-III Module FB1.sch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]
2026-02-02 ignore footprint cache
2026-02-06 PI1551 branding and Microgramma font labels
    [Pi1551-III Module FB1.kicad_pcb, Pi1551-III Module FB2.kicad_pcb, Pi1551-III Module FP1.kicad_pcb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]
2026-02-06 MiniDin connectors from https://forum.kicad.info/t/mini-din-connectors-their-footprints-and-3-d-models-asking-for-discuss
2026-02-07 rotated RPi version to get access to all the ports
    [Pi1551-III Module-rotated.kicad_pcb, Pi1551-III Module-rotated.kicad_sch]
2026-02-07 all 10K resistors to 3.3K, JLPCB part numbers for 470R resistors, 1.2mm track width for 5V - as short as possible
    [Pi1551-III Module-rotated.kicad_pcb, Pi1551-III Module-rotated.kicad_sch, Pi1551-III Module.kicad_pcb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]
2026-02-09 gerber files for fabrication
    [Pi1551-III Module FB1-B_Cu.gbl, Pi1551-III Module FB1-B_Mask.gbs, Pi1551-III Module FB1-B_Paste.gbp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]
2026-03-03 change jumpers to be open - it's too difficult to cut them once panel is soldered in
    [Pi1551-III Module Panel-B_Cu.gbl, Pi1551-III Module Panel-B_Mask.gbs, Pi1551-III Module Panel-B_Paste.gbp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]
2026-03-03 remove base module PCB with RPi in original orientation, no need to keep it
    [Pi1551-III Module-B_Cu.gbl, Pi1551-III Module-B_Mask.gbs, Pi1551-III Module-B_Paste.gbp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]
2026-03-04 no need for duplicated schematic
2026-03-08 Tape cable hint
2026-03-10 revision 2 - pullups on all TCBM lines
    [Pi1551-III Module-rotated-B_Cu.gbl, Pi1551-III Module-rotated-B_Mask.gbs, Pi1551-III Module-rotated-B_Paste.gbp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]
2026-03-10 updated BOM with pullups
    Updated resistor count and description for R4–R24.
